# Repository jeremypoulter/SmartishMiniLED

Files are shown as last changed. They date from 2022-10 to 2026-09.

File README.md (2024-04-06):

# SmartishNight
Electronics for a ESP32/NeoPixel based nightlight

| pin | output |
|-----|---|
| 4 | Button |
| 15  | IR |
| 25  | Data out  |
| 32  | LED power |

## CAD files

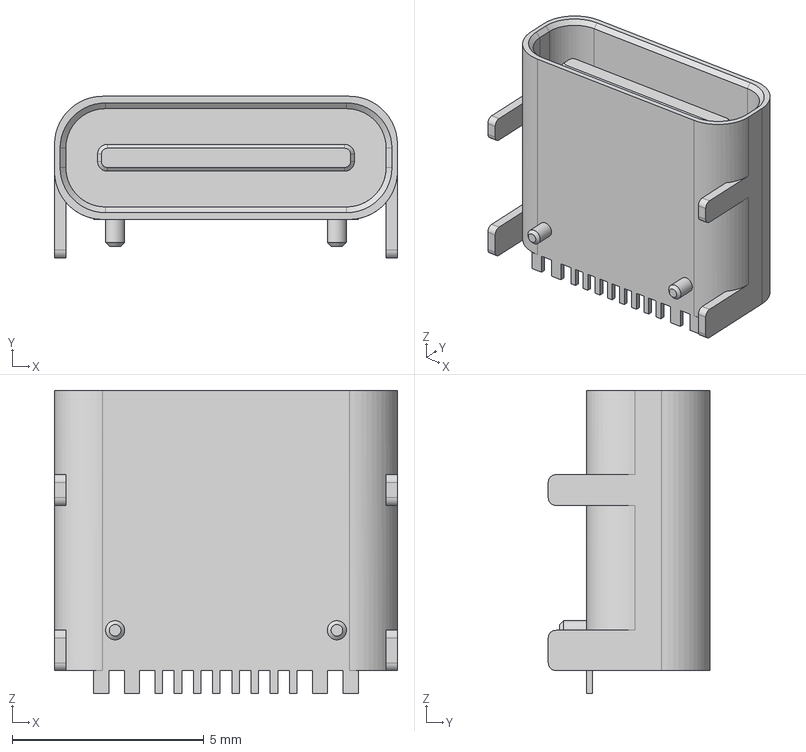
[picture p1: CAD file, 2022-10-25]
HRO-TYPE-C-31-M-12.step
8.94 x 4.21 x 7.90 mm

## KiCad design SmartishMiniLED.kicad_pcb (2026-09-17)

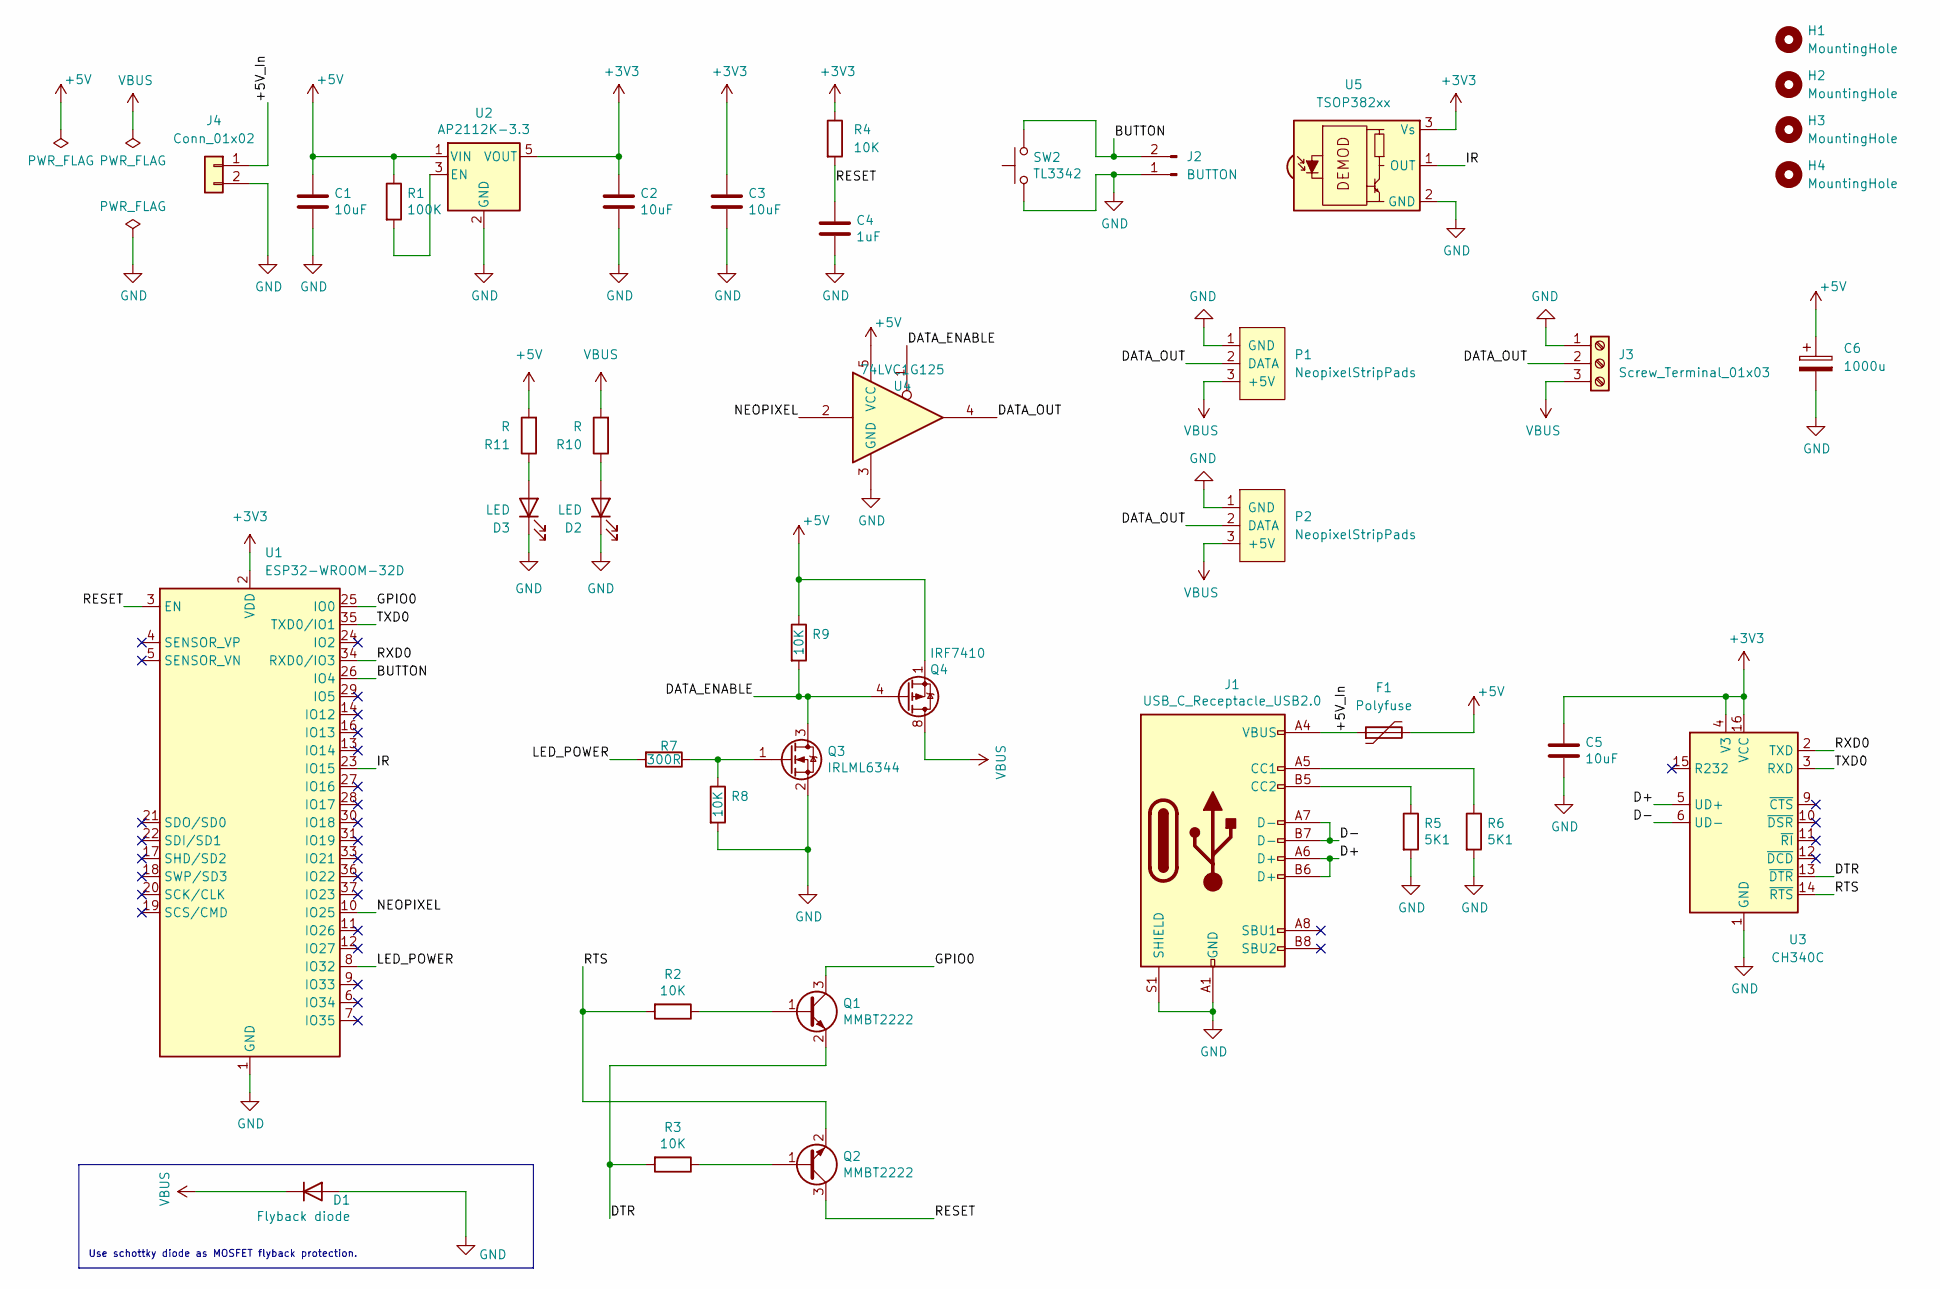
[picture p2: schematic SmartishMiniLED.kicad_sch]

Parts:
C1, C2, C3, C5: 10uF; C_0805_2012Metric; LCSC C15850
C4: 1uF; C_0805_2012Metric; LCSC C15850
C6: 1000u; CP_Elec_10x10; LCSC C176684
D1: Flyback diode; D_SMA_Handsoldering; LCSC C2480
D2, D3: LED; LED_0805_2012Metric
F1: Polyfuse; Fuse_1206_3216Metric; LCSC C207041
H1, H2, H3, H4: MountingHole; MountingHole_3.2mm_M3
J1: USB_C_Receptacle_USB2.0; USB_C_Receptacle_HRO_TYPE-C-31-M-12; LCSC C165948
J2: BUTTON; PinHeader_1x02_P2.54mm_Vertical
J3: Screw_Terminal_01x03; TerminalBlock_TE_282834-3_1x03_P2.54mm_Horizontal
J4: Conn_01x02; Main_Power
P1, P2: NeopixelStripPads; LedStripPads
Q1, Q2: MMBT2222; SOT-23; LCSC C2891810
Q3: IRLML6344; SOT-23; LCSC C693370
Q4: IRF7410; SOIC-8_3.9x4.9mm_P1.27mm; LCSC C148144
R1: 100K; R_0805_2012Metric; LCSC C149504
R2, R3, R8, R9: 10K; R_0805_2012Metric; LCSC C17414
R4: 10K; R_0805_2012Metric
R5, R6: 5K1; R_0805_2012Metric; LCSC C27834
R7: 300R; R_0805_2012Metric; LCSC C352224
R10, R11: R; R_0805_2012Metric
SW2: TL3342; SW_SPST_TL3342; LCSC C318884
U1: ESP32-WROOM-32D; LCSC C473012
U2: AP2112K-3.3; SOT-23-5; LCSC C51118
U3: CH340C; SOIC-16_3.9x9.9mm_P1.27mm; LCSC C84681
U4: 74LVC1G125; SOT-23-5; LCSC C23654
U5: TSOP382xx; Vishay_MINICAST-3Pin

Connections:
+3V3: C2.1, C3.1, C5.1, R4.1, U1.2 (VDD), U2.5 (VOUT), U3.4 (V3), U3.16 (VCC), U5.3 (Vs)
+5V: C1.1, C6.1, F1.2, Q4.1 (S), Q4.2 (S), Q4.3 (S), R1.1, R9.1, R11.2, U2.1 (VIN), U4.5 (VCC)
/+5V_In: F1.1, J1.A4 (VBUS), J1.A9 (VBUS), J1.B4 (VBUS), J1.B9 (VBUS), J4.1
/BUTTON: J2.2, SW2.2, U1.26 (IO4)
/D+: J1.A6 (D+), J1.B6 (D+), U3.5 (UD+)
/D-: J1.A7 (D-), J1.B7 (D-), U3.6 (UD-)
/DATA_ENABLE: Q3.3 (D), Q4.4 (G), R9.2, U4.1
/DATA_OUT: J3.2, P1.2 (DATA), P2.2 (DATA), U4.4
/DTR: Q1.2 (E), R3.2, U3.13 (~DTR)
/GPIO0: Q1.3 (C), U1.25 (IO0)
/IR: U1.23 (IO15), U5.1 (OUT)
/LED_POWER: R7.2, U1.8 (IO32)
/NEOPIXEL: U1.10 (IO25), U4.2
/RESET: C4.1, Q2.3 (C), R4.2, U1.3 (EN)
/RTS: Q2.2 (E), R2.2, U3.14 (~RTS)
/RXD0: U1.34 (RXD0/IO3), U3.2 (TXD)
/TXD0: U1.35 (TXD0/IO1), U3.3 (RXD)
GND: C1.2, C2.2, C3.2, C4.2, C5.2, C6.2, D1.2 (A), D2.1 (K), D3.1 (K), J1.A1 (GND), J1.A12 (GND), J1.B1 (GND), J1.B12 (GND), J1.S1 (SHIELD), J2.1, J3.1, J4.2, P1.1 (GND), P2.1 (GND), Q3.2 (S), R5.2, R6.2, R8.2, SW2.1, U1.1 (GND), U1.15 (GND), U1.38 (GND), U1.39 (GND), U2.2 (GND), U3.1 (GND), U4.3 (GND), U5.2 (GND)
unnamed: D2.2 (A), R10.1
unnamed: D3.2 (A), R11.1
unnamed: J1.A5 (CC1), R6.1
unnamed: J1.B5 (CC2), R5.1
unnamed: Q1.1 (B), R2.1
unnamed: Q2.1 (B), R3.1
unnamed: Q3.1 (G), R7.1, R8.1
unnamed: R1.2, U2.3 (EN)
VBUS: D1.1 (K), J3.3, P1.3 (+5V), P2.3 (+5V), Q4.5 (D), Q4.6 (D), Q4.7 (D), Q4.8 (D), R10.2

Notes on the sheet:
Use schottky diode as MOSFET flyback protection.

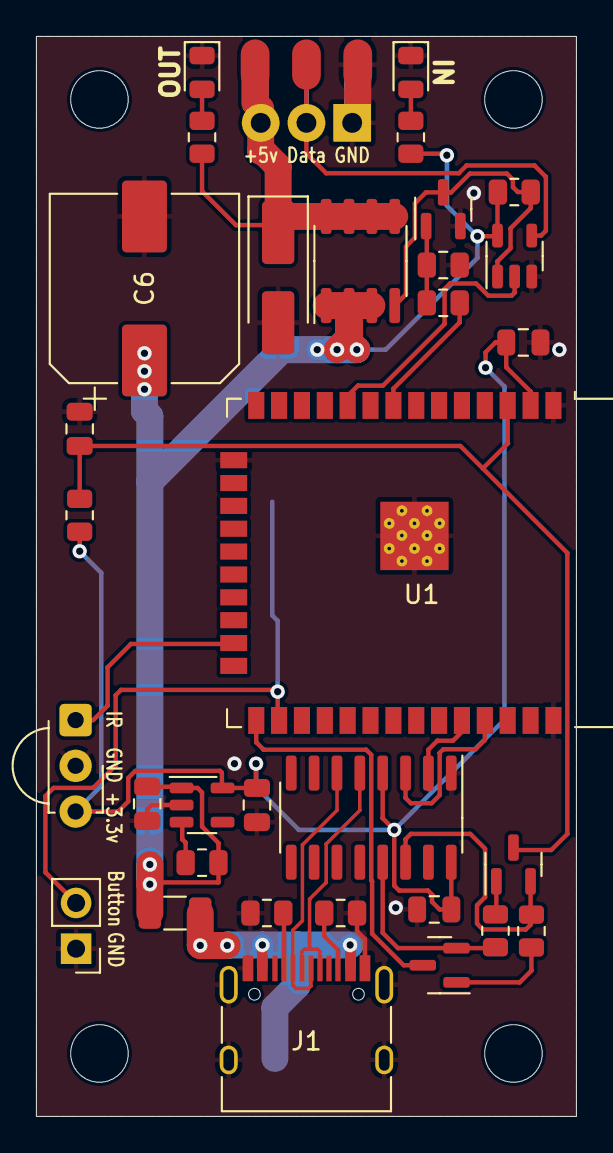
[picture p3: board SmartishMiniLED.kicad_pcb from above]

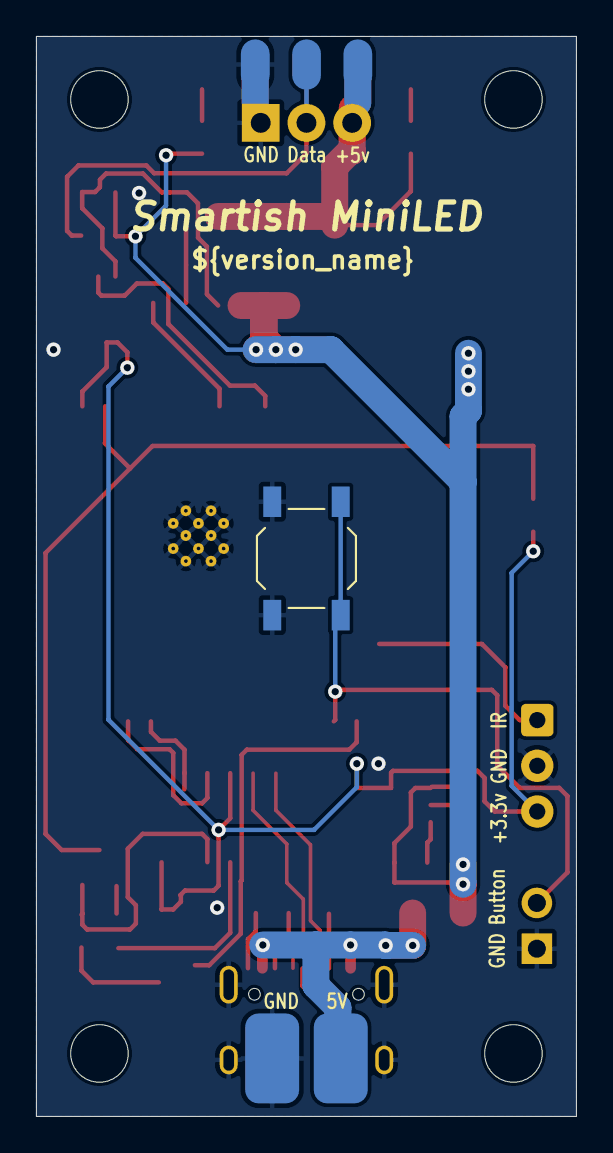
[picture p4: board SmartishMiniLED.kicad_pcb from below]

Board: 2 copper layers, 30.0 x 60.0 mm, 41 parts (3 on the bottom side), 27 nets.

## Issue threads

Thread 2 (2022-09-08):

Reset line needs capacitor and resistor

jeremypoulter, 2022-09-08:

Closed 2023-11-30.

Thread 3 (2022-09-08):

IR pin can't be used

jeremypoulter, 2022-09-08:
Sorry, pins [6,7,8,9,10,11] can't be used.

jeremypoulter, 2022-09-08:
Was looking at an old version of the schematic

Closed 2022-09-08.

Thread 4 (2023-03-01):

Reboot when powering on

jeremypoulter, 2023-03-01:
Every time the power is turned on the ESP32 is rebooted.

jeremypoulter, 2023-03-01:
I think the issue is related to the capacitor being on the LED side of the MOSFET, when the power is turned off the capacitor will discharge. When the MOSFET is turned on the capacitor will charge very quickly, probably causing a brownout.

Closed 2023-11-30.

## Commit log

2022-06-21 Initial import
    Basically a copy of the SmartishNight project with the LEDs removed and a few additional components added (schematic only)
    [SmartishMiniLED.kicad_pcb, SmartishMiniLED.kicad_sch, SmartishMiniLED.sch]
2022-06-29 Remove old v5 files
    [SmartishMiniLED.sch]
2022-06-29 Added MOSFET to switch LED power and fixed ERC errors
    [SmartishMiniLED.kicad_sch]
2022-07-26 WIP Fixed a few bugs in schematic and made a start on the PCB layout
    [SmartishMiniLED.kicad_pcb, SmartishMiniLED.kicad_sch]
2022-08-01 Initial layout
    [SmartishMiniLED.kicad_pcb, SmartishMiniLED.kicad_sch]
2022-08-02 DRC check fixes
    [SmartishMiniLED.kicad_pcb, SmartishMiniLED.kicad_sch]
2022-08-02 DRC fix
    [SmartishMiniLED.kicad_pcb]
2022-08-02 2nd attempt to fix DRC errors
    [SmartishMiniLED.kicad_pcb, SmartishMiniLED.kicad_sch]
2022-08-03 Increased main power line to 1.5mm, should handle 3A
    [SmartishMiniLED.kicad_pcb]
2022-08-03 Added some id text
    [SmartishMiniLED.kicad_pcb]
2022-08-03 A few fixes and tidy ups
    [SmartishMiniLED.kicad_pcb]
2022-08-03 Fix DRC warnings
    [SmartishMiniLED.kicad_pcb]
2022-08-15 Added some pads on the back for as an alternative to supplying the main power.
    [SmartishMiniLED.kicad_pcb, SmartishMiniLED.kicad_sch]
2022-08-20 Updates for production
    [SmartishMiniLED.kicad_pcb, SmartishMiniLED.kicad_sch]
2022-08-20 Fixed DRC errors
    [SmartishMiniLED.kicad_pcb]
2022-08-21 Reworked using the WROOM-32D module
    This allows for easier manufacrure
    [SmartishMiniLED.kicad_pcb, SmartishMiniLED.kicad_sch]
2022-08-21 Fixed 3D models
    [SmartishMiniLED.kicad_pcb]
2022-08-23 Added LCSC part numbers
    [SmartishMiniLED.kicad_sch]
2022-08-23 Part position corrections
    [SmartishMiniLED.kicad_sch]
2022-08-23 More position updates
    [SmartishMiniLED.kicad_sch]
2022-08-24 Updated position corrections
    [SmartishMiniLED.kicad_sch]
2022-08-24 Stopped putting vias directly on pads, can cause productions errors
    [SmartishMiniLED.kicad_pcb]
2022-08-24 Updated teh version number
    [SmartishMiniLED.kicad_pcb, SmartishMiniLED.kicad_sch]
2022-10-17 Added generation of the step file to help with enclosure design
2022-10-25 Adding the USB C connector
    [HRO-TYPE-C-31-M-12.step, SmartishMiniLED.kicad_pcb]
2023-11-09 Various fixes
    - Moved the capacitor to the other side of the MOSFET to fix brownout issues, fixes #4
    - Added extra components needed to fix restart when programming via USB, fixes #2
    [SmartishMiniLED.kicad_pcb, SmartishMiniLED.kicad_sch]
2023-11-09 Adding some power LEDs to help diagnose power issues.
    Also various fixes to checks.
    [SmartishMiniLED.kicad_pcb, SmartishMiniLED.kicad_sch]
2023-11-28 DRC fixes
    [SmartishMiniLED.kicad_pcb]
2023-11-28 Updated to use KiCAD v7
2026-09-17 CI: replace deprecated/archived actions, bump pinned versions (#7)
    * CI: replace deprecated/archived actions, bump pinned versions
    actions/upload-artifact@v3 and actions/download-artifact@v3 are past
    their sunset date and stopped working back in early 2025, so the docs,
    fabrications and release jobs were broken. Bumped both to their current
    majors (v7 upload, v8 download) along with actions/checkout (v4 -> v7).
    v8 download-artifact keeps the same "one subdirectory per artifact"
    layout under `path:` that the release job's packaging script expects,
    so no changes were needed there.
    marvinpinto/action-automatic-releases was archived by its owner in 2024
    and is unmaintained; replaced it with so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
    [SmartishMiniLED.kicad_pcb]
